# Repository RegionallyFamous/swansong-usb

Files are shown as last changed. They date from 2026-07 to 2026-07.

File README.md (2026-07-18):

# SwanSong USB Rev D

SwanSong USB is a turnkey USB-C gamepad conversion of the published SwanTroller
PCB. It preserves the board outline, mounting holes, membrane contacts, and
button layout while replacing the plug-in controller module with a native-USB
PIC16F1459 SOIC circuit that MacroFab can source, program, and assemble.

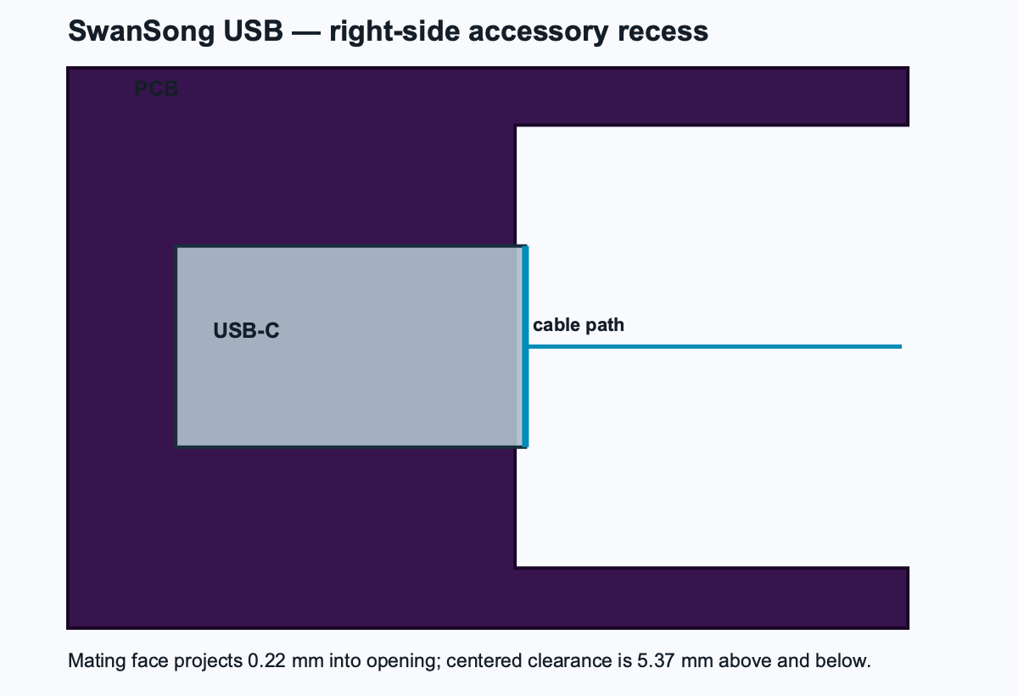
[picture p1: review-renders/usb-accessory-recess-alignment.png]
USB-C aligned to the WonderSwan Color accessory recess


## Manufacturing summary

- Two-layer PCB, bottom-side SMT assembly plus one through-hole USB-C connector
- 9 machine placements, 7 unique BOM lines
- USB-C receptacle is assembled by MacroFab
- USB-C mating face is centered in the WonderSwan Color right-side accessory/
  headphone-adapter recess, with a deliberate 0.22 mm projection into the opening
- No customer-supplied parts and no hand soldering
- A normal USB-C data cable is the only external cable required
- Crystal-free full-speed USB; no oscillator or plug-in MCU board
- MacroFab Standard rules: 10 mil minimum plated drill, 5 mil trace/spacing,
  and a conservative 16 mil copper keepout from the outer route and all nine
  preserved non-plated mechanical-hole edges
- Top and bottom copper are emitted as flattened final artwork; no board-edge
  clear-polarity overlay is left for the factory DRC to reinterpret
- Stocked GCT `USB4085-GF-A` connector has no plastic locating pegs; its 16
  contacts and four shell stakes are ordinary plated holes
- Bottom-side TC2030-PKT-NL Tag-Connect ICSP footprint; spring contacts require
  no installed connector and no soldering
- TC1 is DNL and excluded from placement/BOM data, so it adds no assembly part
- The three TC1 alignment holes and all nine preserved mechanical holes retain
  the same conservative 16 mil copper-to-edge keepout

## Files for MacroFab

- `swansong-usb-gerbers.zip` — copper, mask, paste, silk, outline, and drills
- `swansong-usb.XYRS` — placement data in MacroFab format
- `swansong-usb-bom.csv` — manufacturer part numbers and designators
- `firmware/build/swansong-usb.hex` — combined factory image (bootloader + gamepad)
- `FACTORY_PROGRAMMING.md` — programming and functional-test instructions

The Gerbers and placement files are deterministically generated by
`source/generate_swansong_usb.py`. The preserved GPL-licensed SwanTroller RP2040
Gerbers used as the mechanical/routing base are included in
`source/base-gerbers`, so the repository does not depend on another local checkout.

## Regenerating the release

```sh
python3 -m venv .venv
.venv/bin/pip install -r requirements.txt
.venv/bin/python source/generate_swansong_usb.py
.venv/bin/python source/render_review.py
```

The generator validates same-layer copper clearance, net continuity, via
stitching, preserved top-copper conflicts, connector-body interference, and the
USB-C mating-face position before it writes the manufacturing package.

The reviewed Rev D board renders are in `review-renders/top-rev-d.png` and
`review-renders/bottom-rev-d.png` (the bottom render is mirrored as viewed from
the assembly side).

## Origin and license

This is a July 2026 modified version of Zwenergy's GPL-3.0
[SwanTroller](https://github.com/zwenergy/swantroller). See `NOTICE.md` and
`LICENSE`. Microchip-derived firmware files retain the notices in their headers.

## Firmware and USB updates

The checked-in factory image contains a USB HID bootloader and the relocated
gamepad application. Program `firmware/build/swansong-usb.hex` once through the
solderless Tag-Connect footprint. After that, application releases can be
installed through the normal USB-C connector with:

```sh
python3 -m venv .venv
.venv/bin/pip install -r tools/requirements.txt
.venv/bin/python tools/swansong_usb_update.py firmware/build/swansong-usb-app.hex
```

The updater asks the running gamepad to enter update mode, erases and programs
only the application half of flash, reads every row back, verifies the image
CRC, commits an atomic validity marker, and restarts in gamepad mode. If an
update is interrupted, reconnecting the board returns to the protected
bootloader. Hold **Start + Power** while plugging in USB to force recovery mode.

The combined image has build-time checks for memory boundaries, configuration
words, write protection, reset vectors, image merging, and CRC. It still needs
final electrical/USB testing on an assembled Rev D prototype before a production
quantity is released; a compiler and image validator cannot replace that test.

### SwanSong Studio hardware contract

`tools/swansong_usb_studio.py` is the stable, JSON-only integration boundary
for SwanSong Studio and automated hardware QA. Its read-only commands validate
the exact update image, enumerate the controller without exposing its HID path,
and produce a content-bound update plan:

```sh
.venv/bin/python tools/swansong_usb_studio.py doctor \
  firmware/build/swansong-usb-app.hex
.venv/bin/python tools/swansong_usb_studio.py plan-update \
  firmware/build/swansong-usb-app.hex --version 1.0
```

Installation refuses to touch hardware unless the caller repeats the selected
image's complete SHA-256 and explicitly accepts the controller reset. The
bootloader still performs erase, complete read-back, CRC, atomic validity, and
recovery checks:

```sh
.venv/bin/python tools/swansong_usb_studio.py install \
  firmware/build/swansong-usb-app.hex --version 1.0 \
  --confirm-sha256 SHA256_FROM_PLAN --accept-device-reset
```

An assembled controller can be exercised with `hardware-qa`. It consumes a
bounded number of ordinary three-byte HID reports and passes only after neutral
plus every requested direction and button have actually been observed. It does
not synthesize input or infer a pass from device enumeration:

```sh
.venv/bin/python tools/swansong_usb_studio.py hardware-qa
```

All four commands return versioned deterministic JSON suitable for the Desktop
UI, CI artifact retention, and a future physical-hardware compatibility record.
The engineering VID/PID remains an explicit warning and blocks a commercial
production release until an owned USB identity is assigned.

## USB identity blocker

The engineering HEX uses Microchip's demo USB identity. Prototypes can be built
with it, but a Microchip-assigned PID or an owned VID/PID is required before the
board is sold as a product.

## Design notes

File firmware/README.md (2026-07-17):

# SwanSong USB firmware

This directory builds a recoverable, two-stage firmware system for the
PIC16F1459-I/SO on SwanSong USB Rev D:

- a generic USB HID gamepad (nine buttons and an eight-way hat);
- a driverless USB HID updater;
- a combined image for the first PICkit/Tag-Connect programming operation.

## Release images

| File | Purpose |
| --- | --- |
| `build/swansong-usb.hex` | Combined factory image; use this for a blank chip |
| `build/swansong-usb-factory.hex` | Same combined image, with an explicit name |
| `build/swansong-usb-app.hex` | USB-update image; never use this on a blank chip |
| `build/swansong-usb-bootloader.hex` | Protected bootloader service image |

The lower half of program flash (`0x0000–0x0FFF`) contains the bootloader and is
hardware self-write-protected by `CONFIG2.WRT=HALF`. The gamepad occupies
`0x1000–0x1FDF`. The last 32-word row contains the application boundary, version,
and CRC. That marker is written only after full read-back verification, so an
interrupted update remains in the bootloader.

## Build and verification

From this directory:

```sh
make
make verify
make test
```

`XC8` defaults to `xc8-cc` on `PATH`. If the compiler cannot locate the
PIC12-16F1xxx Device Family Pack automatically, provide its `xc8` directory:

```sh
make XC8=/path/to/xc8-cc DFP=/path/to/PIC12-16F1xxx_DFP/version/xc8
```

The checked-in release was built with MPLAB XC8 4.00 and PIC12-16F1xxx DFP
1.9.258. `make verify` checks both flash boundaries, the reset vectors, the
hardware write-protection bits, the merged application data, and the marker CRC.

## Updating through USB-C

Install the one host dependency from the repository root:

```sh
python3 -m venv .venv
.venv/bin/pip install -r tools/requirements.txt
```

Then connect the controller and run:

```sh
.venv/bin/python tools/swansong_usb_update.py firmware/build/swansong-usb-app.hex
```

The tool validates the HEX before touching the device, switches the gamepad into
update mode, erases/programs/verifies every application row, commits the CRC
marker, and restarts the controller. No soldering or programmer is needed after
the initial combined image has been installed. See `UPDATE_PROTOCOL.md` for the
wire format used by the CLI and future SwanSong Desktop integration.

Recovery options:

- Hold **Start + Power** while connecting USB to force the HID bootloader.
- If the protected bootloader itself is ever damaged by external ICSP, use a
  PICkit 5 and `TC2030-PKT-NL` cable to reinstall `swansong-usb.hex`.

## Controls

- D-pad: X1 up, X2 right, X3 down, X4 left
- Buttons 1–9: A, B, Y1, Y2, Y3, Y4, Start, Sound, Power
- Input reports: 3 bytes, one 8-way hat plus nine buttons
- Debounce: 5 ms, sampled from USB Start-of-Frame timing

## USB identity warning

The engineering build uses Microchip's demo VID with application PID `005E` and
bootloader PID `005F`. These values are suitable only for prototypes. Obtain a
licensed/owned VID and PIDs, update the shared constants in
`common/swansong_update.h`, rebuild, and re-run all checks before commercial sale.

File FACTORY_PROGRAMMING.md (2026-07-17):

# SwanSong USB Rev D — factory programming and test

## Programming

- Device: Microchip PIC16F1459-I/SO
- Image: `swansong-usb.hex` at the programming-package root (combined bootloader + gamepad)
- Preferred prototype method: program U1 before placement to avoid fixture NRE
- Standard solderless method: high-voltage ICSP through bottom footprint `TC1`
- Cable: Tag-Connect `TC2030-PKT-NL` for PICkit 3/4/5
- TC1 pin 1: VPP/MCLR
- TC1 pin 2: VDD/VBUS
- TC1 pin 3: GND
- TC1 pin 4: PGD/ICSPDAT (A / RC0 / U1 pin 16)
- TC1 pin 5: PGC/ICSPCLK (B / RC1 / U1 pin 15)
- TC1 pin 6: not connected; LVP is disabled
- TC1 is DNL: do not install a connector or apply solder paste
- Configuration: MCLR disabled at runtime, LVP disabled, internal oscillator with 3x PLL
- Self-write protection: `0000h–0FFFh` protected; USB updates can write only `1000h–1FFFh`

For the lowest NRE at prototype quantity, MacroFab may pre-program U1 before
placement. If MacroFab instead uses TC1 in circuit, it should control VDD and VPP
sequencing per the PIC16F1459 programming specification. TC1 uses spring-loaded
contacts, so neither the factory nor the customer solders a programming header.
All programming and assembly remain MacroFab-supplied; no customer-supplied
parts are required.

## USB update and recovery

`swansong-usb.hex` contains the protected HID bootloader, relocated gamepad, and
validated application marker. After this one ICSP operation, normal releases use
`swansong-usb-app.hex` through the USB-C port. Holding Start + Power while USB is
connected forces recovery/update mode. An interrupted update leaves the marker
invalid and the controller in its bootloader. TC1 remains the solderless recovery
path if external ICSP ever damages the bootloader itself.

The image is compiler- and structure-verified but must be electrically qualified
on an assembled Rev D prototype before a production quantity is released.

## Functional test

1. Connect the assembled PCB to a USB 2.0 host with a normal USB-C data cable.
2. Confirm enumeration as `SwanSong USB`, generic HID gamepad, one IN endpoint.
3. Confirm neutral report is `00 00 08`.
4. Exercise X1/X2/X3/X4 and confirm hat values north/east/south/west and diagonals.
5. Exercise A, B, Y1, Y2, Y3, Y4, Start, Sound, and Power individually.
6. Confirm opposite D-pad directions cancel to neutral on that axis.
7. Flex the USB-C cable lightly and confirm there is no disconnect.
8. Hold Start + Power while reconnecting and confirm enumeration as
   `SwanSong USB Update`, then reconnect normally and confirm gamepad mode.

The development image uses VID/PID `04D8:005E` for the gamepad and `04D8:005F`
for the updater; replace both PIDs with assigned production values before sale.

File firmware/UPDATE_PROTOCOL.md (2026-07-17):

# SwanSong USB update protocol v1

This document is the host-side contract implemented by
`bootloader/bootloader.c` and `tools/swansong_usb_update.py`. It is intentionally
simple enough to add to SwanSong Desktop without a kernel driver.

## USB modes

- Gamepad: HID `04D8:005E`, product `SwanSong USB`.
- Updater: HID `04D8:005F`, product `SwanSong USB Update`, one 64-byte interrupt
  OUT report and one 64-byte interrupt IN report, no report IDs.
- To leave gamepad mode, send the eight-byte HID feature report
  `53 53 55 50 01 42 4C A5`. The gamepad waits 25 USB frames, executes the PIC
  `RESET` instruction, and the bootloader enumerates under the updater PID.
- Holding Start + Power during connection forces updater mode.

HIDAPI expects a leading zero report-ID byte in front of both the feature report
and 64-byte OUT reports. That byte is transport metadata and is not delivered to
the PIC.

## 64-byte command report

| Byte | Meaning |
| --- | --- |
| 0 | Magic `0x53` |
| 1 | Protocol version `0x01` |
| 2 | Command |
| 3 | Sequence number, echoed by the response |
| 4–5 | Little-endian PIC program-word address |
| 6–7 | Command arguments |
| 8–39 | Up to 16 little-endian 14-bit PIC words |
| 40–63 | Reserved, send zero |

The response uses the same header, with bit 7 set in the command. Byte 4 is the
status (`0` for success). Every command has exactly one response.

| Command | Value | Operation |
| --- | --- | --- |
| Query | `0x01` | Return bootloader version, row size, bounds, and validity |
| Erase row | `0x02` | Erase one aligned 32-word application row |
| Write half | `0x03` | Stage half 0 or 1; half 1 commits and verifies the row |
| Read half | `0x04` | Return 16 words for host read-back verification |
| Finalize | `0x05` | Verify CRC, write the atomic marker, and validate again |
| Reset | `0x06` | Leave updater mode only when a valid application exists |

For Finalize, bytes 4–5 contain the final application address (`0x1FDF`), bytes
6–7 contain CRC-16/CCITT-FALSE, and bytes 8–9 contain major/minor version bytes.
CRC starts at `0xFFFF`, uses polynomial `0x1021`, and covers the low byte then
high byte of every 14-bit word from `0x1000` through `0x1FDF`; absent HEX words
are `0x3FFF`.

## Safety properties

- `CONFIG2.WRT=HALF` prevents self-write to bootloader words `0x0000–0x0FFF`.
- All bootloader erase/write commands independently reject lower-half addresses.
- The marker row (`0x1FE0–0x1FFF`) is erased before an update and committed only
  after device-side CRC verification.
- The bootloader recomputes CRC on every normal boot. A missing or bad marker
  keeps the controller in updater mode.

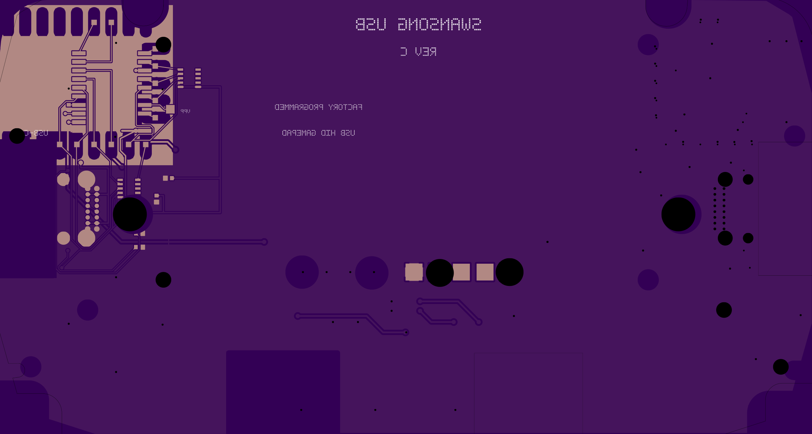
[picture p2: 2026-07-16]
review-renders/bottom-rev-c.png

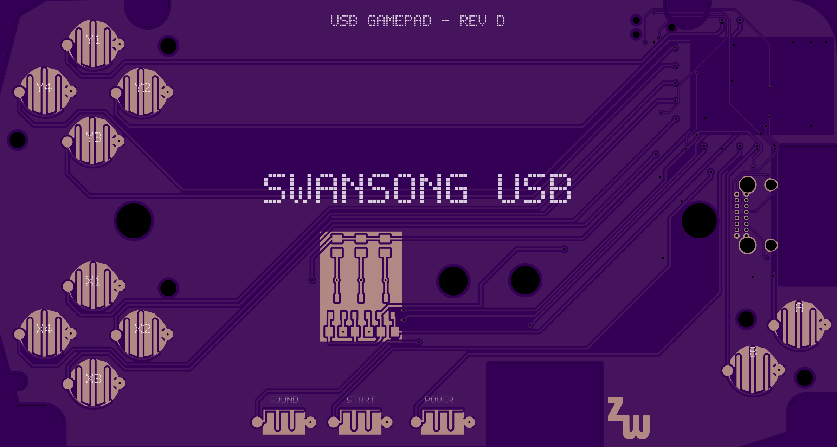
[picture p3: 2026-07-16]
review-renders/top-rev-d.png

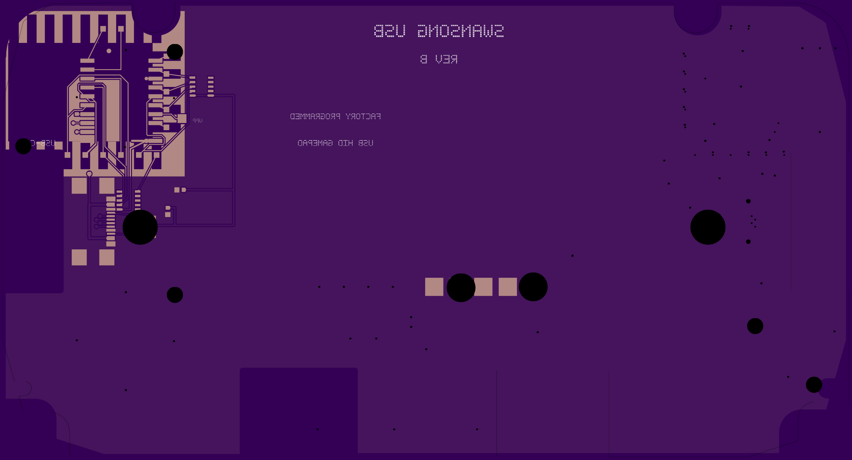
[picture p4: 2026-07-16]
review-renders/bottom-rev-b.png

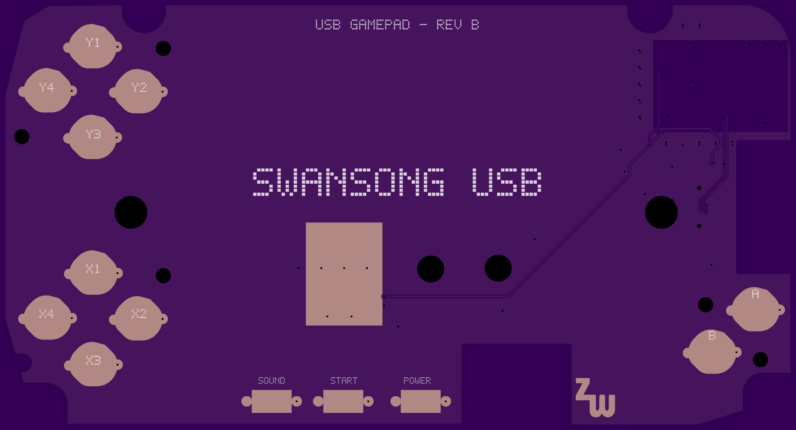
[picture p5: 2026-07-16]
review-renders/top-rev-b.png

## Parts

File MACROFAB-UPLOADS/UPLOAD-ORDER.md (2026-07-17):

# SwanSong USB — MacroFab upload order

Project: SwanSong USB — Rev D

1. On the Design page, upload `01-swansong-usb-gerbers.zip`.
2. Confirm the 11 imported manufacturing layers: top/bottom copper, top/bottom solder mask, top/bottom silkscreen, top/bottom paste, board outline, PTH drill, and NPTH drill.
3. Confirm the Design Rule Check shows the Standard lane: 10 mil plated drill, at least 5 mil copper spacing, and at least 10 mil copper-to-edge clearance. This revision emits flattened final copper with a 16 mil keepout around the outside route, all nine preserved non-plated mechanical holes, and TC1's three 39 mil non-plated alignment holes. J1 has no locating pegs; all 20 of its holes are plated.
4. Upload `02-swansong-usb-bom.xlsx` when MacroFab asks for the bill of materials.
5. Upload `03-swansong-usb-placement.XYRS` when MacroFab asks for placement data.
6. Set every component to MacroFab-supplied inventory; do not select customer-supplied parts. U1 is the SOIC part `PIC16F1459-I/SO`, and J1 is the stocked GCT through-hole connector `USB4085-GF-A`.
7. Ask MacroFab for turnkey programming and functional test, using `04-swansong-usb-firmware-and-test.zip`. Pre-programming U1 before placement is preferred at prototype quantity.
8. Confirm TC1 is DNL: it must not appear as a BOM or placement item and must receive no solder paste. Its six exposed bottom pads and three asymmetric alignment holes are the solderless ICSP interface.
9. Before ordering, visually verify the bottom-side placement and rotation of J1 (USB-C), U1, RN1, and RN2. J1's mating face must project slightly into the center of the right-side accessory/headphone-adapter recess.

The firmware package contains the combined protected bootloader and gamepad
image. It uses Microchip's development VID with gamepad PID `005E` and updater
PID `005F`; obtain assigned production values before commercial release.

The combined image passes compiler, memory-boundary, configuration-word,
read-back-protocol, and CRC tests. Electrically qualify USB gamepad and update/
recovery behavior on an assembled Rev D prototype before releasing production
quantity.

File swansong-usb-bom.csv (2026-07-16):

Quantity | Designators | Manufacturer Part Number | Description | Package | Manufacturer
1 | U1 | PIC16F1459-I/SO | PIC16F1459 | SOIC-20 | Microchip Technology
1 | J1 | USB4085-GF-A | USB-C 2.0 receptacle | GCT USB4085 PTH | GCT
2 | RN1, RN2 | 746X101103JP | 8x10k bussed resistor array | 1206 10-pin bussed array | CTS Resistor Products
2 | R1, R2 | RC0402FR-075K1L | 5.1k 1% | 0402 | Yageo
1 | C1 | CC0402KRX7R7BB104 | 0.1uF 16V X7R | 0402 | Yageo
1 | C2 | CC0402KRX7R6BB105 | 1uF 10V X7R | 0402 | Yageo
1 | C3 | CC0402KRX5R5BB474 | 0.47uF 6.3V X5R | 0402 | Yageo

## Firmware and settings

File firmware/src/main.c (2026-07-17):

/********************************************************************
 FileName:      main.c
 Dependencies:  See INCLUDES section
 Processor:     PIC18, PIC24, dsPIC, and PIC32 USB Microcontrollers
 Hardware:      This demo is natively intended to be used on Microchip USB demo
                boards supported by the MCHPFSUSB stack.  See release notes for
                support matrix.  This demo can be modified for use on other 
                hardware platforms.
 Complier:      Microchip C18 (for PIC18), XC16 (for PIC24/dsPIC), XC32 (for PIC32)
 Company:       Microchip Technology, Inc.

 Software License Agreement:

 The software supplied herewith by Microchip Technology Incorporated
 (the "Company") for its PIC(R) Microcontroller is intended and
 supplied to you, the Company's customer, for use solely and
 exclusively on Microchip PIC Microcontroller products. The
 software is owned by the Company and/or its supplier, and is
 protected under applicable copyright laws. All rights are reserved.
 Any use in violation of the foregoing restrictions may subject the
 user to criminal sanctions under applicable laws, as well as to
 civil liability for the breach of the terms and conditions of this
 license.

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
********************************************************************
 File Description:

 Change History:
  Rev   Description
  ----  -----------------------------------------
  2.8   Improvements to USBCBSendResume(), to make it easier to use.
  2.9   Added remote wakeup capability to the demo.
  2.9f  Adding new part support
  2.9j  Updates to support new bootloader features (ex: app version 
        fetching).
********************************************************************/

#ifndef JOYSTICKMAIN_C
#define JOYSTICKMAIN_C

/** INCLUDES *******************************************************/
#include "./USB/usb.h"
#include "HardwareProfile.h"
#include "./USB/usb_function_hid.h"
#include "../common/swansong_update.h"

/** CONFIGURATION **************************************************/
#if defined(PICDEM_FS_USB)      // Configuration bits for PICDEM FS USB Demo Board (based on PIC18F4550)
        #pragma config PLLDIV   = 5         // (20 MHz crystal on PICDEM FS USB board)
        #if (USB_SPEED_OPTION == USB_FULL_SPEED)
            #pragma config CPUDIV   = OSC1_PLL2  
        #else
            #pragma config CPUDIV   = OSC3_PLL4   
        #endif
        #pragma config USBDIV   = 2         // Clock source from 96MHz PLL/2
        #pragma config FOSC     = HSPLL_HS
        #pragma config FCMEN    = OFF
        #pragma config IESO     = OFF
        #pragma config PWRT     = OFF
        #pragma config BOR      = ON
        #pragma config BORV     = 3
        #pragma config VREGEN   = ON      //USB Voltage Regulator
        #pragma config WDT      = OFF
        #pragma config WDTPS    = 32768
        #pragma config MCLRE    = ON
        #pragma config LPT1OSC  = OFF
        #pragma config PBADEN   = OFF
//      #pragma config CCP2MX   = ON
        #pragma config STVREN   = ON
        #pragma config LVP      = OFF
//      #pragma config ICPRT    = OFF       // Dedicated In-Circuit Debug/Programming
        #pragma config XINST    = OFF       // Extended Instruction Set
        #pragma config CP0      = OFF
        #pragma config CP1      = OFF
//      #pragma config CP2      = OFF
//      #pragma config CP3      = OFF
        #pragma config CPB      = OFF
//      #pragma config CPD      = OFF
        #pragma config WRT0     = OFF
        #pragma config WRT1     = OFF
//      #pragma config WRT2     = OFF
//      #pragma config WRT3     = OFF
        #pragma config WRTB     = OFF       // Boot Block Write Protection
        #pragma config WRTC     = OFF
//      #pragma config WRTD     = OFF
        #pragma config EBTR0    = OFF
        #pragma config EBTR1    = OFF
//      #pragma config EBTR2    = OFF
//      #pragma config EBTR3    = OFF
        #pragma config EBTRB    = OFF

#elif defined(PICDEM_FS_USB_K50)
        #pragma config PLLSEL   = PLL3X     // 3X PLL multiplier selected
        #pragma config CFGPLLEN = OFF       // PLL turned on during execution
        #pragma config CPUDIV   = NOCLKDIV  // 1:1 mode (for 48MHz CPU)
        #pragma config LS48MHZ  = SYS48X8   // Clock div / 8 in Low Speed USB mode
        #pragma config FOSC     = INTOSCIO  // HFINTOSC selected at powerup, no clock out
        #pragma config PCLKEN   = OFF       // Primary oscillator driver
        #pragma config FCMEN    = OFF       // Fail safe clock monitor
        #pragma config IESO     = OFF       // Internal/external switchover (two speed startup)
        #pragma config nPWRTEN  = OFF       // Power up timer
        #pragma config BOREN    = SBORDIS   // BOR enabled
        #pragma config nLPBOR   = ON        // Low Power BOR
        #pragma config WDTEN    = SWON      // Watchdog Timer controlled by SWDTEN
        #pragma config WDTPS    = 32768     // WDT postscalar
        #pragma config PBADEN   = OFF       // Port B Digital/Analog Powerup Behavior
        #pragma config SDOMX    = RC7       // SDO function location
        #pragma config LVP      = OFF       // Low voltage programming
        #pragma config MCLRE    = ON        // MCLR function enabled (RE3 disabled)
        #pragma config STVREN   = ON        // Stack overflow reset
        //#pragma config ICPRT  = OFF       // Dedicated ICPORT program/debug pins enable
        #pragma config XINST    = OFF       // Extended instruction set

#elif defined(PIC18F87J50_PIM)				// Configuration bits for PIC18F87J50 FS USB Plug-In Module board
        #pragma config XINST    = OFF   	// Extended instruction set
        #pragma config STVREN   = ON      	// Stack overflow reset
        #pragma config PLLDIV   = 3         // (12 MHz crystal used on this board)
        #pragma config WDTEN    = OFF      	// Watch Dog Timer (WDT)
        #pragma config CP0      = OFF      	// Code protect
        #pragma config CPUDIV   = OSC1      // OSC1 = divide by 1 mode
        #pragma config IESO     = OFF      	// Internal External (clock) Switchover
        #pragma config FCMEN    = OFF      	// Fail Safe Clock Monitor
        #pragma config FOSC     = HSPLL     // Firmware must also set OSCTUNE<PLLEN> to start PLL!
        #pragma config WDTPS    = 32768
//      #pragma config WAIT     = OFF      	// Commented choices are
//      #pragma config BW       = 16      	// only available on the
//      #pragma config MODE     = MM      	// 80 pin devices in the 
//      #pragma config EASHFT   = OFF      	// family.
        #pragma config MSSPMSK  = MSK5
//      #pragma config PMPMX    = DEFAULT
//      #pragma config ECCPMX   = DEFAULT
        #pragma config CCP2MX   = DEFAULT   
        
// Configuration bits for PIC18F97J94 PIM and PIC18F87J94 PIM
#elif defined(PIC18F97J94_PIM) || defined(PIC18F87J94_PIM)
        #pragma config STVREN   = ON      	// Stack overflow reset
        #pragma config XINST    = OFF   	// Extended instruction set
        #pragma config BOREN    = ON        // BOR Enabled
        #pragma config BORV     = 0         // BOR Set to "2.0V" nominal setting
        #pragma config CP0      = OFF      	// Code protect disabled
        #pragma config FOSC     = FRCPLL    // Firmware should also enable active clock tuning for this setting
        #pragma config SOSCSEL  = LOW       // SOSC circuit configured for crystal driver mode
        #pragma config CLKOEN   = OFF       // Disable clock output on RA6
        #pragma config IESO     = OFF      	// Internal External (clock) Switchover
        #pragma config PLLDIV   = NODIV     // 4 MHz input (from 8MHz FRC / 2) provided to PLL circuit
        #pragma config POSCMD   = NONE      // Primary osc disabled, using FRC
        #pragma config FSCM     = CSECMD    // Clock switching enabled, fail safe clock monitor disabled
        #pragma config WPDIS    = WPDIS     // Program memory not write protected
        #pragma config WPCFG    = WPCFGDIS  // Config word page of program memory not write protected
        #pragma config IOL1WAY  = OFF       // IOLOCK can be set/cleared as needed with unlock sequence
        #pragma config LS48MHZ  = SYSX2     // Low Speed USB clock divider
        #pragma config WDTCLK   = LPRC      // WDT always uses INTOSC/LPRC oscillator
        #pragma config WDTEN    = ON        // WDT disabled; SWDTEN can control WDT
        #pragma config WINDIS   = WDTSTD    // Normal non-window mode WDT.
        #pragma config VBTBOR   = OFF       // VBAT BOR disabled
      
#elif defined(PIC18F46J50_PIM) || defined(PIC18F_STARTER_KIT_1) || defined(PIC18F47J53_PIM)
     #pragma config WDTEN = OFF          //WDT disabled (enabled by SWDTEN bit)
     #pragma config PLLDIV = 3           //Divide by 3 (12 MHz oscillator input)
     #pragma config STVREN = ON          //stack overflow/underflow reset enabled
     #pragma config XINST = OFF          //Extended instruction set disabled
     #pragma config CPUDIV = OSC1        //No CPU system clock divide
     #pragma config CP0 = OFF            //Program memory is not code-protected
     #pragma config OSC = HSPLL          //HS oscillator, PLL enabled, HSPLL used by USB
     #pragma config FCMEN = OFF          //Fail-Safe Clock Monitor disabled
     #pragma config IESO = OFF           //Two-Speed Start-up disabled
     #pragma config WDTPS = 32768        //1:32768
     #pragma config DSWDTOSC = INTOSCREF //DSWDT uses INTOSC/INTRC as clock
     #pragma config RTCOSC = T1OSCREF    //RTCC uses T1OSC/T1CKI as clock
     #pragma config DSBOREN = OFF        //Zero-Power BOR disabled in Deep Sleep
     #pragma config DSWDTEN = OFF        //Disabled
     #pragma config DSWDTPS = 8192       //1:8,192 (8.5 seconds)
     #pragma config IOL1WAY = OFF        //IOLOCK bit can be set and cleared
     #pragma config MSSP7B_EN = MSK7     //7 Bit address masking
     #pragma config WPFP = PAGE_1        //Write Protect Program Flash Page 0
     #pragma config WPEND = PAGE_0       //Start protection at page 0
     #pragma config WPCFG = OFF          //Write/Erase last page protect Disabled
     #pragma config WPDIS = OFF          //WPFP[5:0], WPEND, and WPCFG bits ignored 
     #if defined(PIC18F47J53_PIM)
        #pragma config CFGPLLEN = OFF
     #else
        #pragma config T1DIG = ON           //Sec Osc clock source may be selected
        #pragma config LPT1OSC = OFF        //high power Timer1 mode
     #endif
#elif defined(LOW_PIN_COUNT_USB_DEVELOPMENT_KIT)
        #pragma config CPUDIV = NOCLKDIV
        #pragma config USBDIV = OFF
        #pragma config FOSC   = HS
        #pragma config PLLEN  = ON
        #pragma config FCMEN  = OFF
        #pragma config IESO   = OFF
        #pragma config PWRTEN = OFF
        #pragma config BOREN  = ON
        #pragma config BORV   = 30
        #pragma config WDTEN  = OFF
        #pragma config WDTPS  = 32768
        #pragma config MCLRE  = OFF
        #pragma config HFOFST = OFF
        #pragma config STVREN = ON
        #pragma config LVP    = OFF
        #pragma config XINST  = OFF
        #pragma config BBSIZ  = OFF
        #pragma config CP0    = OFF
        #pragma config CP1    = OFF
        #pragma config CPB    = OFF
        #pragma config WRT0   = OFF
        #pragma config WRT1   = OFF
        #pragma config WRTB   = OFF
        #pragma config WRTC   = OFF
        #pragma config EBTR0  = OFF
        #pragma config EBTR1  = OFF
        #pragma config EBTRB  = OFF        

#elif	defined(PIC16F1_LPC_USB_DEVELOPMENT_KIT)
#if !defined(SWANSONG_BOOTLOADED_APPLICATION)
    /* Crystal-free 16 MHz HFINTOSC x3 = 48 MHz. High-voltage ICSP remains
       available at the VPP test pad even though MCLR is disabled at runtime. */
    #pragma config FOSC = INTOSC, WDTE = OFF, PWRTE = ON, MCLRE = OFF
    #pragma config CP = OFF, BOREN = ON, CLKOUTEN = OFF, IESO = OFF, FCMEN = OFF
    #pragma config WRT = OFF, CPUDIV = NOCLKDIV, USBLSCLK = 48MHz
    #pragma config PLLMULT = 3x, PLLEN = ENABLED, STVREN = ON
    #pragma config BORV = LO, LPBOR = OFF, LVP = OFF
#endif
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
int main(void)
#endif
{   
    InitializeSystem();

    #if defined(USB_INTERRUPT)
        USBDeviceAttach();
    #endif

    while(1)
    {
        #if defined(USB_POLLING)
		// Check bus status and service USB interrupts.
        USBDeviceTasks(); // Interrupt or polling method.  If using polling, must call
        				  // this function periodically.  This function will take care
        				  // of processing and responding to SETUP transactions 
        				  // (such as during the enumeration process when you first
        				  // plug in).  USB hosts require that USB devices should accept
        				  // and process SETUP packets in a timely fashion.  Therefore,
        				  // when using polling, this function should be called 
        				  // regularly (such as once every 1.8ms or faster** [see 
        				  // inline code comments in usb_device.c for explanation when
        				  // "or faster" applies])  In most cases, the USBDeviceTasks() 
        				  // function does not take very long to execute (ex: <100 
        				  // instruction cycles) before it returns.
        #endif
    				  

		// Application-specific tasks.
		// Application related code may be added here, or in the ProcessIO() function.
        ProcessIO();        
    }//end while
}//end main


/********************************************************************
 * Function:        static void InitializeSystem(void)
 *
 * PreCondition:    None
 *
 * Input:           None
 *
 * Output:          None
 *
 * Side Effects:    None
 *
 * Overview:        InitializeSystem is a centralize initialization
 *                  routine. All required USB initialization routines
 *                  are called from here.
 *
 *                  User application initialization routine should
 *                  also be called from here.                  
 *
 * Note:            None
 *******************************************************************/
static void InitializeSystem(void)
{
    #if defined(_PIC14E)
        //Configure all pins for digital mode, except RB4, which has a POT on it
        ANSELA = 0x00;
        #if defined(_16F1459) || defined(_16LF1459)
            ANSELB = 0x00;
        #endif
        ANSELC = 0x00;
        #if defined (USE_INTERNAL_OSC)
            OSCTUNE = 0;
            OSCCON = 0xFC;          //16MHz HFINTOSC with 3x PLL enabled (48MHz operation)
            ACTCON = 0x90;          //Enable active clock tuning with USB
        #endif
    #endif

    #if (defined(__18CXX) & !defined(PIC18F87J50_PIM) & !defined(PIC18F97J94_FAMILY))
        ADCON1 |= 0x0F;                 // Default all pins to digital
    #elif defined(__C30__) || defined __XC16__
        #if defined(__PIC24FJ256GB110__) || defined(__PIC24FJ256GB106__)
            AD1PCFGL = 0xFFFF;
     #elif defined(__dsPIC33EP512MU810__)||defined(__PIC24EP512GU810__)
        	ANSELA = 0x0000;
    		ANSELB = 0x0000;
    		ANSELC = 0x0000;
    		ANSELD = 0x0000;
    		ANSELE = 0x0000;
    		ANSELG = 0x0000;
            
            // The dsPIC33EP512MU810 features Peripheral Pin
            // select. The following statements map UART2 to 
            // device pins which would connect to the the 
            // RX232 transciever on the Explorer 16 board.

             RPINR19 = 0;
             RPINR19 = 0x64;
             RPOR9bits.RP101R = 0x3;

        #endif
    #elif defined(__C32__)
        AD1PCFG = 0xFFFF;
    #endif

    #if defined(PIC18F87J50_PIM) || defined(PIC18F46J50_PIM) || defined(PIC18F_STARTER_KIT_1) || defined(PIC18F47J53_PIM)
	//On the PIC18F87J50 Family of USB microcontrollers, the PLL will not power up and be enabled
	//by default, even if a PLL enabled oscillator configuration is selected (such as HS+PLL).
	//This allows the device to power up at a lower initial operating frequency, which can be
	//advantageous when powered from a source which is not gauranteed to be adequate for 48MHz
	//operation.  On these devices, user firmware needs to manually set the OSCTUNE<PLLEN> bit to
	//power up the PLL.
    {
        unsigned int pll_startup_counter = 600;
        OSCTUNEbits.PLLEN = 1;  //Enable the PLL and wait 2+ms until the PLL locks before enabling USB module
        while(pll_startup_counter--);
    }
    //Device switches over automatically to PLL output after PLL is locked and ready.
    #endif

    #if defined(PIC18F87J50_PIM)
	//Configure all I/O pins to use digital input buffers.  The PIC18F87J50 Family devices
	//use the ANCONx registers to control this, which is different from other devices which
	//use the ADCON1 register for this purpose.
    WDTCONbits.ADSHR = 1;			// Select alternate SFR location to access ANCONx registers
    ANCON0 = 0xFF;                  // Default all pins to digital
    ANCON1 = 0xFF;                  // Default all pins to digital
    WDTCONbits.ADSHR = 0;			// Select normal SFR locations
    #endif

    #if defined(PIC18F97J94_FAMILY)
        //Configure I/O pins for digital input mode.
        ANCON1 = 0xFF;
        ANCON2 = 0xFF;
        ANCON3 = 0xFF;
        #if(USB_SPEED_OPTION == USB_FULL_SPEED)
            //Enable INTOSC active clock tuning if full speed
            ACTCON = 0x90; //Enable active clock self tuning for USB operation
            while(OSCCON2bits.LOCK == 0);   //Make sure PLL is locked/frequency is compatible
                                            //with USB operation (ex: if using two speed 
                                            //startup or otherwise performing clock switching)
        #endif
    #endif
    
    #if defined(PIC18F45K50_FAMILY)
        //Configure oscillator settings for clock settings compatible with USB 
        //operation.  Note: Proper settings depends on USB speed (full or low).
        #if(USB_SPEED_OPTION == USB_FULL_SPEED)
            OSCTUNE = 0x80; //3X PLL ratio mode selected
            OSCCON = 0x70;  //Switch to 16MHz HFINTOSC
            OSCCON2 = 0x10; //Enable PLL, SOSC, PRI OSC drivers turned off
            while(OSCCON2bits.PLLRDY != 1);   //Wait for PLL lock
            *((unsigned char*)0xFB5) = 0x90;  //Enable active clock tuning for USB operation
        #endif
    #endif

    #if defined(PIC18F46J50_PIM) || defined(PIC18F_STARTER_KIT_1) || defined(PIC18F47J53_PIM)
	//Configure all I/O pins to use digital input buffers.  The PIC18F87J50 Family devices
	//use the ANCONx registers to control this, which is different from other devices which
	//use the ADCON1 register for this purpose.
    ANCON0 = 0xFF;                  // Default all pins to digital
    ANCON1 = 0xFF;                  // Default all pins to digital
    #endif
    
   #if defined(PIC24FJ64GB004_PIM) || defined(PIC24FJ256DA210_DEV_BOARD)
	//On the PIC24FJ64GB004 Family of USB microcontrollers, the PLL will not power up and be enabled
	//by default, even if a PLL enabled oscillator configuration is selected (such as HS+PLL).
	//This allows the device to power up at a lower initial operating frequency, which can be
	//advantageous when powered from a source which is not gauranteed to be adequate for 32MHz
	//operation.  On these devices, user firmware needs to manually set the CLKDIV<PLLEN> bit to
	//power up the PLL.
    {
        unsigned int pll_startup_counter = 600;
        CLKDIVbits.PLLEN = 1;
        while(pll_startup_counter--);
    }

    //Device switches over automatically to PLL output after PLL is locked and ready.
    #endif
    
    #if defined(__32MX460F512L__)|| defined(__32MX795F512L__)
    // Configure the PIC32 core for the best performance
    // at the operating frequency. The operating frequency is already set to 
    // 60MHz through Device Config Registers
    SYSTEMConfigPerformance(60000000);
	#endif
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

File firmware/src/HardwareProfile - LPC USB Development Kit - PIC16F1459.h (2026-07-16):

#ifndef HARDWARE_PROFILE_SWANSONG_USB_H
#define HARDWARE_PROFILE_SWANSONG_USB_H

/* SwanSong USB Rev A: PIC16F1459, crystal-free full-speed USB. */
#define USE_INTERNAL_OSC
#define DEMO_BOARD PIC16F1_LPC_USB_DEVELOPMENT_KIT
#define PIC16F1_LPC_USB_DEVELOPMENT_KIT
#define CLOCK_FREQ 48000000UL
#define _XTAL_FREQ 48000000UL

/* This is a USB bus-powered device. */
#define self_power 0
#define USB_BUS_SENSE 1

/* The production PCB has no LEDs and no separate demo switches. */
#define mInitAllLEDs() do { } while (0)
#define mInitAllSwitches() do { } while (0)
#define mLED_1_Toggle() do { } while (0)
#define mLED_1_On() do { } while (0)
#define mLED_1_Off() do { } while (0)
#define mLED_2_On() do { } while (0)
#define mLED_2_Off() do { } while (0)
#define mGetLED_1() 0
#define sw2 1
#define sw3 1

#define INPUT_PIN 1
#define OUTPUT_PIN 0

/* Active-low membrane contacts. Port A/B use internal pull-ups; the eight
   Port C controls use the two external bussed 10k arrays on the PCB. */
#define BTN_Y4      PORTAbits.RA4
#define BTN_Y3      PORTCbits.RC5
#define BTN_SOUND   PORTCbits.RC4
#define BTN_X1      PORTCbits.RC3
#define BTN_X3      PORTCbits.RC6
#define BTN_X2      PORTCbits.RC7
#define BTN_X4      PORTBbits.RB7
#define BTN_Y2      PORTBbits.RB6
#define BTN_Y1      PORTBbits.RB5
#define BTN_START   PORTBbits.RB4
#define BTN_POWER   PORTCbits.RC2
#define BTN_B       PORTCbits.RC1
#define BTN_A       PORTCbits.RC0

#endif

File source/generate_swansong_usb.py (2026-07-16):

#!/usr/bin/env python3
"""Generate the SwanSong USB turnkey MacroFab manufacturing package.

The published controller source contains Gerbers but no editable PCB source.  This
script preserves the proven board outline, mounting holes, membrane contacts, and
button routing; removes the RP2040 module and SNES-output assembly; then adds a
native-USB PIC16F1459 circuit in the former module area.

Coordinates are kept in the source Gerbers' native inch system.  The output is a
complete, deterministic set of RS-274X/Excellon files plus placement/BOM CSVs.
"""

from __future__ import annotations

import csv
import hashlib
import heapq
import json
import math
import re
import shutil
import sys
from dataclasses import dataclass
from pathlib import Path
from typing import Iterable

from shapely.affinity import scale as scale_geometry
from shapely.geometry import LineString, Point, Polygon, box
from shapely.ops import unary_union


HERE = Path(__file__).resolve().parent
PROJECT = HERE.parent
sys.path.insert(0, str(HERE))

from gerber_geometry import component_for_point, load_layer  # noqa: E402


BASE = HERE / "base-gerbers"
OUT = PROJECT / "gerbers"

TRACE_W = 0.0050      # 0.127 mm (5 mil)
CLEARANCE = 0.0050    # 0.127 mm; MacroFab Standard minimum
VIA_PAD = 0.0260      # 0.660 mm
VIA_DRILL = 0.0120    # 0.305 mm
SMALL_VIA_PAD = 0.0200   # 0.508 mm
SMALL_VIA_DRILL = 0.0100 # 0.254 mm; MacroFab Standard minimum
MASK_EXPAND = 0.0030  # 0.076 mm per side
EDGE_COPPER_CLEARANCE = 0.0160  # 0.406 mm; margin above MacroFab's 10 mil minimum
USB_PIN_DRILL = 0.40 / 25.4
USB_PIN_PAD = 0.66 / 25.4  # 5.1 mil annular ring; above MacroFab Standard
USB_REAR_SHELL_DRILL = 2.20 / 25.4
USB_REAR_SHELL_PAD = 2.46 / 25.4
USB_FRONT_SHELL_DRILL = 1.55 / 25.4
USB_FRONT_SHELL_PAD = 1.81 / 25.4
TAG_CONTACT_DIAMETER = 0.0310
TAG_ALIGNMENT_DRILL = 0.0390
TAG_CX = 4.00
TAG_CY = 5.90
REVISION = "D"

# The new top-layer routing keepouts split the original ground pour at this
# diagonal neck. Gerber coordinate rounding otherwise leaves two fragments
# only 0.679 mil apart, which MacroFab reports as an outer-copper spacing
# violation even though both fragments are GND. A short 5 mil bridge restores
# the original ground connection while remaining more than 10 mil from every
# unrelated copper feature.
TOP_GROUND_BRIDGE = [(2.17836, 4.74072), (2.17884, 4.74120)]

# The WonderSwan Color exposes its accessory connector on the right side of the
# shell.  The preserved controller outline has the matching rectangular recess
# from X=4.720 in to the outer edge and Y=4.455..5.230 in.  Keep the USB-C
# receptacle centered in that opening and preserve the proven front-edge offset
# used by Rev A, which leaves the connector mouth safely inside the opening.
ACCESSORY_RECESS_INNER_X = 4.720
ACCESSORY_RECESS_Y_MIN = 4.455
ACCESSORY_RECESS_Y_MAX = 5.230
USB_FRONT_X = ACCESSORY_RECESS_INNER_X + 0.008625
USB_BODY_LENGTH = 9.17 / 25.4
USB_CX = USB_FRONT_X - USB_BODY_LENGTH / 2
USB_CY = (ACCESSORY_RECESS_Y_MIN + ACCESSORY_RECESS_Y_MAX) / 2
USB_BODY_HALF_LENGTH = USB_BODY_LENGTH / 2
USB_BODY_HALF_WIDTH = 4.47 / 25.4


@dataclass(frozen=True)
class Pad:
    ref: str
    number: str
    net: str
    x: float
    y: float
    width: float
    height: float
    paste: bool = True
    mask: bool = True
    round: bool = False
    through_hole: bool = False

    @property
    def shape(self):
        if self.round:
            return Point(self.x, self.y).buffer(self.width / 2, resolution=24)
        return box(
            self.x - self.width / 2,
            self.y - self.height / 2,
            self.x + self.width / 2,
            self.y + self.height / 2,
        )


@dataclass(frozen=True)
class Placement:
    ref: str
    value: str
    mpn: str
    x: float
    y: float
    rotation: float
    side: str = "Bottom"
    package: str = ""


def rect_pad(ref, number, net, x, y, width_mm, height_mm, **kwargs):
    return Pad(ref, str(number), net, x, y, width_mm / 25.4, height_mm / 25.4, **kwargs)


def round_pad(ref, number, net, x, y, diameter_mm, **kwargs):
    diameter = diameter_mm / 25.4
    return Pad(ref, str(number), net, x, y, diameter, diameter, round=True, **kwargs)


def line_shape(points: list[tuple[float, float]], width=TRACE_W):
    return LineString(points).buffer(width / 2, resolution=12, cap_style=1, join_style=1)


def minimum_component_spacing(shape):
    """Return the smallest positive gap between disconnected copper islands."""
    components = list(shape.geoms) if shape.geom_type == "MultiPolygon" else [shape]
    best = math.inf
    for index, left in enumerate(components):
        for right in components[index + 1:]:
            distance = left.distance(right)
            if 1e-9 < distance < best:
                best = distance
    return best


def circle_shape(x, y, diameter):
    return Point(x, y).buffer(diameter / 2, resolution=24)


def xy(value: float) -> int:
    return round(value * 1_000_000)


def gerber_header(layer_name: str) -> str:
    return (
        f"G04 SwanSong USB - {layer_name}*\n"
        "G04 Generated from the published SwanTroller Gerbers; units inches*\n"
        "%FSLAX36Y36*%\n"
        "%MOIN*%\n"
        "%ADD10C,0.001*%\n"
        "%LPD*%\n"
    )


def polygon_region(poly: Polygon) -> str:
    coords = list(poly.exterior.coords)
    if len(coords) < 4:
        return ""
    out = ["G36*", "G01*", f"X{xy(coords[0][0])}Y{xy(coords[0][1])}D02*"]
    out.extend(f"X{xy(x)}Y{xy(y)}D01*" for x, y in coords[1:])
    out.append("G37*")
    return "\n".join(out) + "\n"


def geometry_regions(geometry, polarity: str) -> str:
    if geometry.is_empty:
        return ""
    geoms = list(geometry.geoms) if geometry.geom_type in {"MultiPolygon", "GeometryCollection"} else [geometry]
    out = [f"%LP{'D' if polarity == 'dark' else 'C'}*%\n"]
    for geom in geoms:
        if geom.is_empty:
            continue
        if geom.geom_type != "Polygon":
            geom = geom.buffer(0)
        polys = list(geom.geoms) if geom.geom_type == "MultiPolygon" else [geom]
        for poly in polys:
            out.append(polygon_region(poly))
            # New geometries in this design do not intentionally contain holes,
            # but preserve them correctly if a union operation creates one.
            for interior in poly.interiors:
                out.append(f"%LP{'C' if polarity == 'dark' else 'D'}*%\n")
                out.append(polygon_region(Polygon(interior)))
                out.append(f"%LP{'D' if polarity == 'dark' else 'C'}*%\n")
    return "".join(out)
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

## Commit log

2026-07-16 Initial SwanSong USB hardware release
    [02-swansong-usb-bom.xlsx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]
2026-07-16 Rev C: use turnkey PTH USB-C and Standard DRC clearances
    [02-swansong-usb-bom.xlsx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]
2026-07-16 Flatten copper artwork for MacroFab edge DRC
    [Gerber_BottomLayer.GBL, Gerber_TopLayer.GTL]
2026-07-16 Add solderless Tag-Connect ICSP interface
    [Drill_NPTH_Through.DRL, Drill_PTH_Through.DRL, Gerber_BottomLayer.GBL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]
2026-07-16 Fix MacroFab outer copper spacing
    [Gerber_TopLayer.GTL]
